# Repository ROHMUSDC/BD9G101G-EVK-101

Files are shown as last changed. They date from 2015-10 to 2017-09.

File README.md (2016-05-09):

# BD9G101G-EVK-101 Design Resource Repository
* Hardware Design Files and Documentation for the ROHM BD9G101G-EVK-101 EVK

----
### Description: 
* The BD9G101G is switching regulator with integrated internal high-side 42V Power MOSFET.
* This IC provides 0.5A DC output in a small SOT-23 package.
* Operating frequency is fixed 1.5MHz, allowing the use of small inductor and ceramic capacitor.
* The components for phase compensation is built in. 
* The BD9G101G is available in SOT-23-6(SSOP6) package.

----
### Repository Contents
* User's Guide: Contains the User's Guide for this EVK
* Design Files: Contains Schematic, BOM, and Gerber information for this EVK Board
* Supplemental Info Folder: Contains General Presentation and HotPlugging Analysis for this EVK Board

----
### Where to Purchase?
* http://www.rohm.com/web/global/distribution/-/dinventory/BD9G101G-EVK/sample/0

----
### DISCLAIMER
This Technical Data is protected under copyright laws.

ROHM hereby grants you a nonexclusive, nontransferable license to use this Technical Data 
as long as you abide by the terms and conditions of this DISCLAIMER. 

However, you are not authorized to sell, loan, rent, lease, redistribute or license this Technical Data, 
in whole or in part, or in modified form, to anyone.

You may modify this Technical Data to suit your specific applications, 
but the rights to derivative works and said modifications shall belong to ROHM. 

You may make copies of this Technical Data as necessary for internal use only within your company.

In any case, the latest datasheet is considered the final design guideline and represents 
the only actual performance specifications.

ROHM shall not be responsible for ensuring proper application on all computer systems.
This Technical Data is provided AS IS. ROHM makes no guarantees, either implicitly or explicitly, 
regarding its usability, functionality, accuracy, merchantability, or fitness for a specific purpose.

In addition, you shall take full responsibility for the use of any information acquired from this Technical Data. 

ROHM does not assume warranty of any kind arising from the use of this Technical Data. ACCORDINGLY, 
IN NO EVENT SHALL ROHM BE RESPONSIBLE, WHETHER THROUGH CONTRACT OR TORT LIABILITY, 
FOR ANY DAMAGES (INCLUDING BUT NOT LIMITED TO LOST PROFITS OR OTHER INCIDENTAL, CONSEQUENTAL, 
OR PUNITIVE DAMAGES) ARISING OUT OF OR IN CONNECTION WITH THE USE OR APPLICATION OF THIS Technical Data.

Furthermore, this Technical Data is subject to change without notice.

Unless otherwise expressly provided herein, ROHM does not convey any license under patent rights 
or any other intellectual property rights (including those of third parties).

ROHM is not obligated to provide maintenance or support for the Technical Data.

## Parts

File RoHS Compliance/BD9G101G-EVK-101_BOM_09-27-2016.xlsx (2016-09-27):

BOM for BD9G101G |  |  |  |  |  |  |  | FAB/ASSY RoHS Certificate of Compliance:
Part Designator | Value | Package | Supplier | Part Number | DK P/N | Cost | RoHS Reference Documentation | FAB-9_FAB-ASSY_RoHS Cert.pdf
D1 | 60V, 2A | SOD-123F | ROHM | RB060M-60 | RB060M-60CT-ND (http://www.digikey.com/product-detail/en/RB060M-60TR/RB060M-60CT-ND/2615676) |  | RoHS Compliance Letter_20131212.pdf
CIN1 | 4.7uF, 50V | 1206 | Murata | GRM31CF51H475ZA01L | 490-1828-1-ND (http://www.digikey.com/product-detail/en/GRM31CF51H475ZA01L/490-1828-1-ND/587362) |  | Murata_CO2E_100112-558472.pdf
CO2 | 10uF, 10V | 1206 | Murata | GRM31CR61A106KA01L | 490-1820-1-ND |  | Murata_CO2E_100112-558472.pdf
SW1 | 30V, 0.2A | Vert, through hole | E-Switch | EG1218 | EG1903-ND |  | Series_EG1218_Cert_revA_.pdf
R1 | 68k | 0805 | Yageo | RC0805FR-0768KL | 311-68.0KCRCT-ND (http://www.digikey.com/product-detail/en/RC0805FR-0768KL/311-68.0KCRCT-ND/731045) |  | RoHS_Compliance_YAGEO.pdf
R2 | 12k | 0805 | Yageo | RC0805FR-0712KL | 311-12.0KCRCT-ND (http://www.digikey.com/product-detail/en/RC0805FR-0712KL/311-12.0KCRCT-ND/730515) |  | RoHS_Compliance_YAGEO.pdf
LX | 10uH | SOD-106 | TOKO | DEM4518C 1235AS-H-100M |  |  | TOKO_rohs_rist_e.pdf
U1 | 5V, 0.5A | SSOP6 | ROHM | BDG101G |  |  | RoHS Compliance Letter_20131212.pdf
CIN2 | 30V TVS | SMA |  | SMAJ30ALFCT |  |  | LittelFuse_ChinaRoHS_SMAJ _SMCJ _SMDJ _5 0SMDJ _1 5SMC _P4SMA.pdf
Vcc, Vout |  |  |  | Red Test Pin |  |  | N/A
GND |  |  |  | Black Test Pin |  |  | N/A

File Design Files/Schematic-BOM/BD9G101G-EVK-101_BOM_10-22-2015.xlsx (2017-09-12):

BOM for BD9G101G
Part Designator | Value | Package | Supplier | Part Number | DK P/N | Cost
D1 | 60V, 2A | SOD-123F | ROHM | RB060M-60 | RB060M-60CT-ND (http://www.digikey.com/product-detail/en/RB060M-60TR/RB060M-60CT-ND/2615676)
CIN1 | 4.7uF, 50V | 1206 | Murata | GRM31CF51H475ZA01L | 490-1828-1-ND (http://www.digikey.com/product-detail/en/GRM31CF51H475ZA01L/490-1828-1-ND/587362)
CO2 | 10uF, 10V | 1206 | Murata | GRM31CR61A106KA01L | 490-1820-1-ND
SW1 | 30V, 0.2A | Vert, through hole | E-Switch | EG1218 | EG1903-ND
R1 | 68k | 0805 | Yageo | RC0805FR-0768KL | 311-68.0KCRCT-ND (http://www.digikey.com/product-detail/en/RC0805FR-0768KL/311-68.0KCRCT-ND/731045)
R2 | 12k | 0805 | Yageo | RC0805FR-0712KL | 311-12.0KCRCT-ND (http://www.digikey.com/product-detail/en/RC0805FR-0712KL/311-12.0KCRCT-ND/730515)
LX | 10uH | SOD-106 | TOKO | DEM4518C 1235AS-H-100M | 490-14207-1-ND
U1 | 5V, 0.5A | SSOP6 | ROHM | BD9G101G | BD9G101G-CT-ND
CIN2 | 30V TVS | SMA | ROHM | SMAJ30ALFCT | SMAJ30ALFCT-ND
CBST | 0.015uF, 50V, X7R | 0603 | Murata | GRM188R71H153KA01D | 490-1514-1-ND
JEN | short | 0603 | ROHM | MCR03ERTJ000 | RHM0.0CGTR-ND
RFRA | short | 0603 | ROHM | MCR03ERTJ000 | RHM0.0CGTR-ND
RFB | short | 0603 | ROHM | MCR03ERTJ000 | RHM0.0CGTR-ND
Vcc, Vout | TP | Via | Keystone | Red Test Pin | 36-5005-ND
GND | TP | Via | Keystone | Black Test Pin | 36-5006-ND

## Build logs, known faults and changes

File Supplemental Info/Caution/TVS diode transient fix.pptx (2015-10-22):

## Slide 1

TVS Diode to prevent transient spikes at Vcc with BD9G101G Eval board

BD9G101G: VCC(max): 45V, 42V (operating)

- Vcc = 35V, ceramic cap only, 72V transient spike (cursors show 45V max limit), NOT GOOD

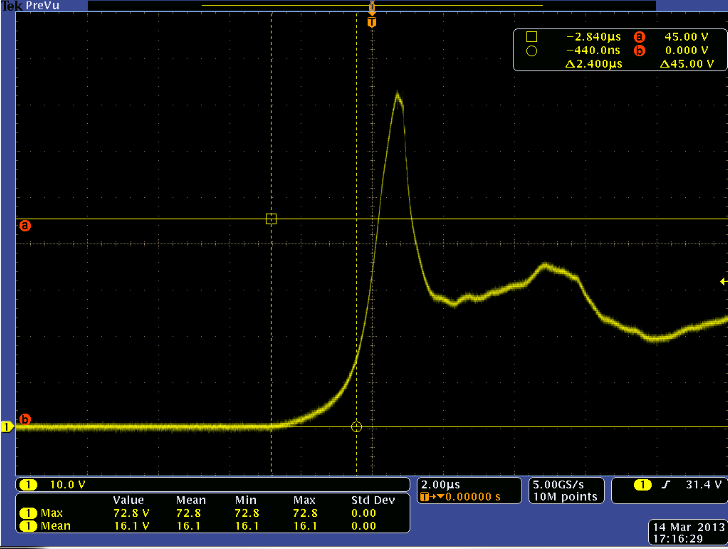
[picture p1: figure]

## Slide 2

TVS Diode 30V 400W 5% Results:

A. Vcc=35V, 44Vpk clamp, GOOD

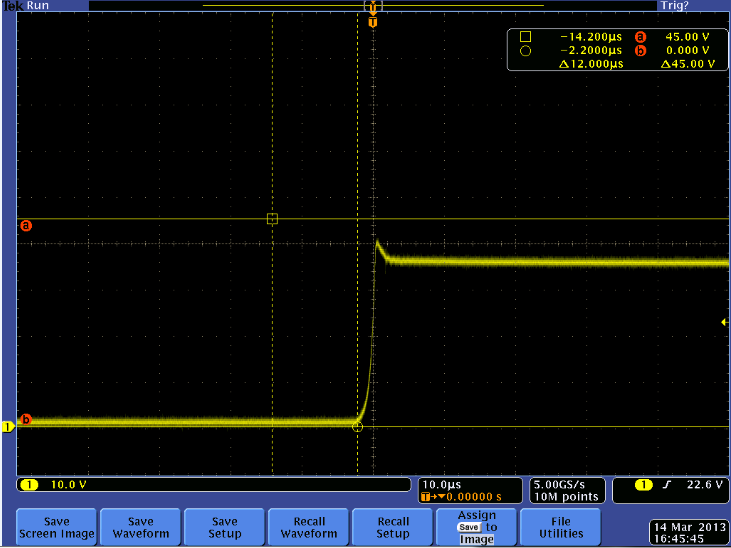
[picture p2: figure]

B. Vcc=30V, 40Vpk transient, GOOD

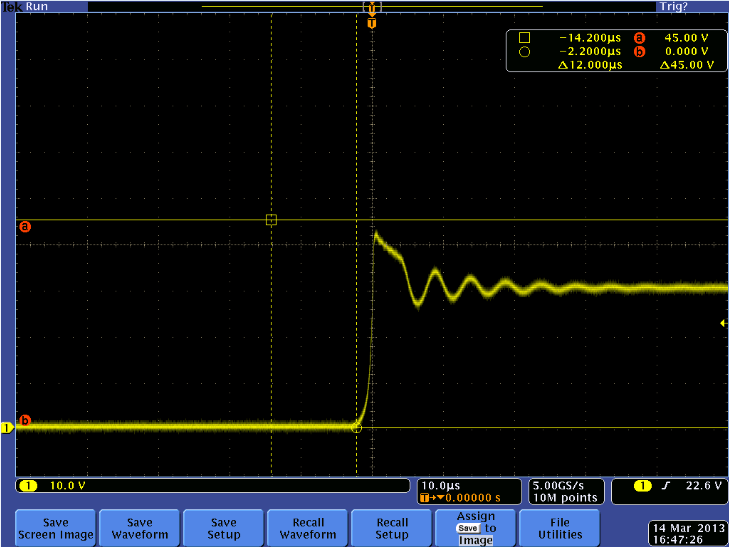
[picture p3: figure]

C. Vcc=25V, 40Vpk transient, GOOD

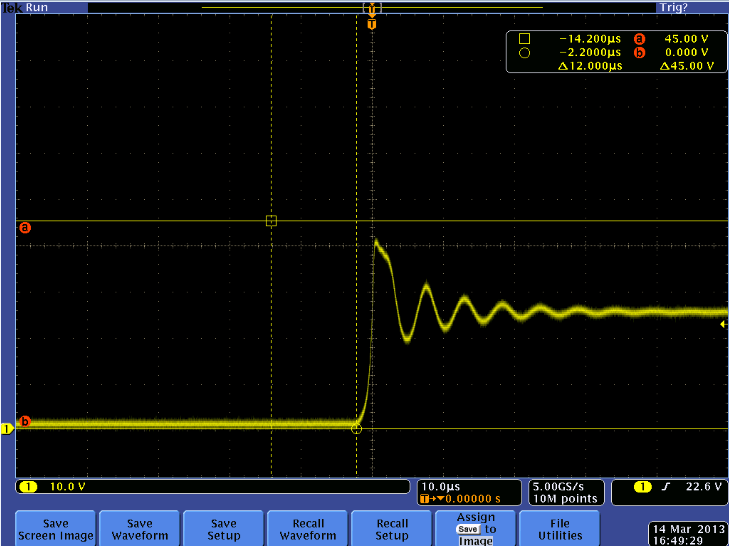
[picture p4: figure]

D. Vcc=20V, 28Vpk transient, GOOD

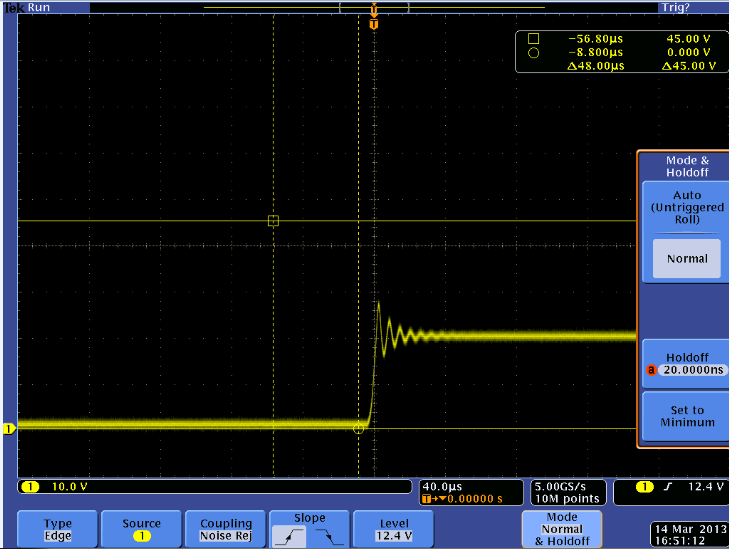
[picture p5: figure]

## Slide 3

Data:

Vcc (V) | Transient Peak Voltage
| 40V TVS Diode | IC Status | 30V TVS Diode | IC Status
20 | 40 | OK | 30 | OK
25 | 50 | OK | 40 | OK
30 | 55 | NG | 40 | OK
35 | n/a | NG | 44 | OK
40 | n/a | NG | 46 | OK
45 | n/a | NG | 50 | OK

Previously, the IC was destroyed with a 27-30V hot plug on Vcc. Goal is to protect eval board from destruction while increasing Vcc operating range.
Conclusion:
30V TVS diode should be used in parallel with the ceramic input cap to prevent 45V+ transient peaks at Vcc. A higher value diode can be used to increase the operating range, but this will increase the chances of the IC being destroyed at those higher voltages. Eval board limit in manual will be 35Vin. In the lab, up to 45Vin was used on the board with the diode and the board survived after (20 hot plug tests).

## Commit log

2015-10-22 Initial Commit
    Added Design files, Application Note, and Supplemental Information
    Section to the Repository
    [BD9G101G-EVK-101_BOM_10-22-2015.xlsx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]
2016-09-27 Added RoHS Compliance Information
    Added folder named "RoHS Compliance" to root of this repository. Adds
    an updated BOM with RoHS Compliance field and all related RoHS
    documentation including both parts and fab/assembly process.
    [BD9G101G-EVK-101_BOM_09-27-2016.xlsx]
2017-07-17 Updated Layout and BOM
    Found some mismatches in the BOM and added the fixes. Also, updated
    Layout to use the files with the corrected silkscreen.
    [BD9G101G-EVK-101_BOM_10-22-2015.xlsx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]
2017-09-12 Updated BOM
    Added CBST reference to BOM
    [BD9G101G-EVK-101_BOM_10-22-2015.xlsx]
